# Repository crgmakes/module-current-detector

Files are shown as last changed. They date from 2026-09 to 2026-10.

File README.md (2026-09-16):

# Current Detector Module

All the source files for the current detector module hardware.

# Software 

You will need [KiCad](https://kicad.org) to view and edit this design. Click [here](https://www.kicad.org/download/) to download.

You will also need all the associated libraries and models to drive the design if you want to make changes or view the 3D rendering:

https://github.com/crgmakes/kicad-library.git

Kicad MUST be configured properly to use all the files in this repo. Once you have Kicad installed, under Preferences->Configure Paths..., make the following entries:

1. - KICAD_USER_DIR -> set to the root location of where you placed the above repository.
2. - KICAD_USER_LIBRARY = ${KICAD_USER_DIR}/Library
3. - KICAD_USER_MODEL_DIR = ${KICAD_USER_LIBRARY}/models
4. - KICAD_USER_TEMPLATE_DIR	= ${KICAD_USER_LIBRARY}/templates	

Kicad will operate mostly normally if these are not set properly. You will notice an issue when you view the PCB in 3D mode.

***NOTE***: after makeing a release build in git, if your rendered 3D images are missing components, ensure the path to EVERY component model is set to ${KICAD_USER_MODEL_DIR}/<model name>.

Kicad sometimes replaces the variable with an expansion and that FAILS during the build process because the expanded variable is local and does not match the build environment.

---

THE DESIGN IS PROVIDED "AS IS" AND THE AUTHOR DISCLAIMS ALL WARRANTIES WITH REGARD TO THIS DESIGN INCLUDING ALL IMPLIED WARRANTIES OF MERCHANTABILITY AND FITNESS. IN NO EVENT SHALL THE AUTHOR BE LIABLE FOR ANY SPECIAL, DIRECT, INDIRECT, OR CONSEQUENTIAL DAMAGES OR ANY DAMAGES WHATSOEVER RESULTING FROM LOSS OF USE, DATA OR PROFITS, WHETHER IN AN ACTION OF CONTRACT, NEGLIGENCE OR OTHER TORTIOUS ACTION, ARISING OUT OF OR IN CONNECTION WITH THE USE OR PERFORMANCE OF THIS DESIGN.

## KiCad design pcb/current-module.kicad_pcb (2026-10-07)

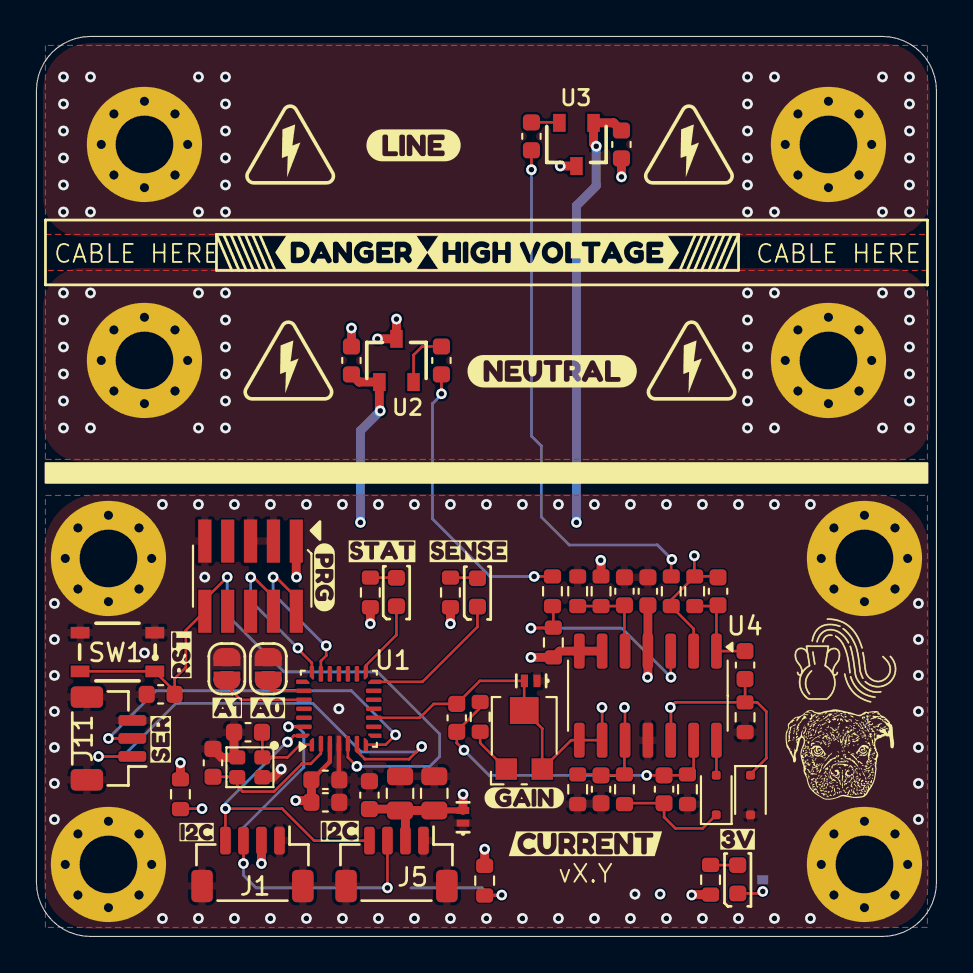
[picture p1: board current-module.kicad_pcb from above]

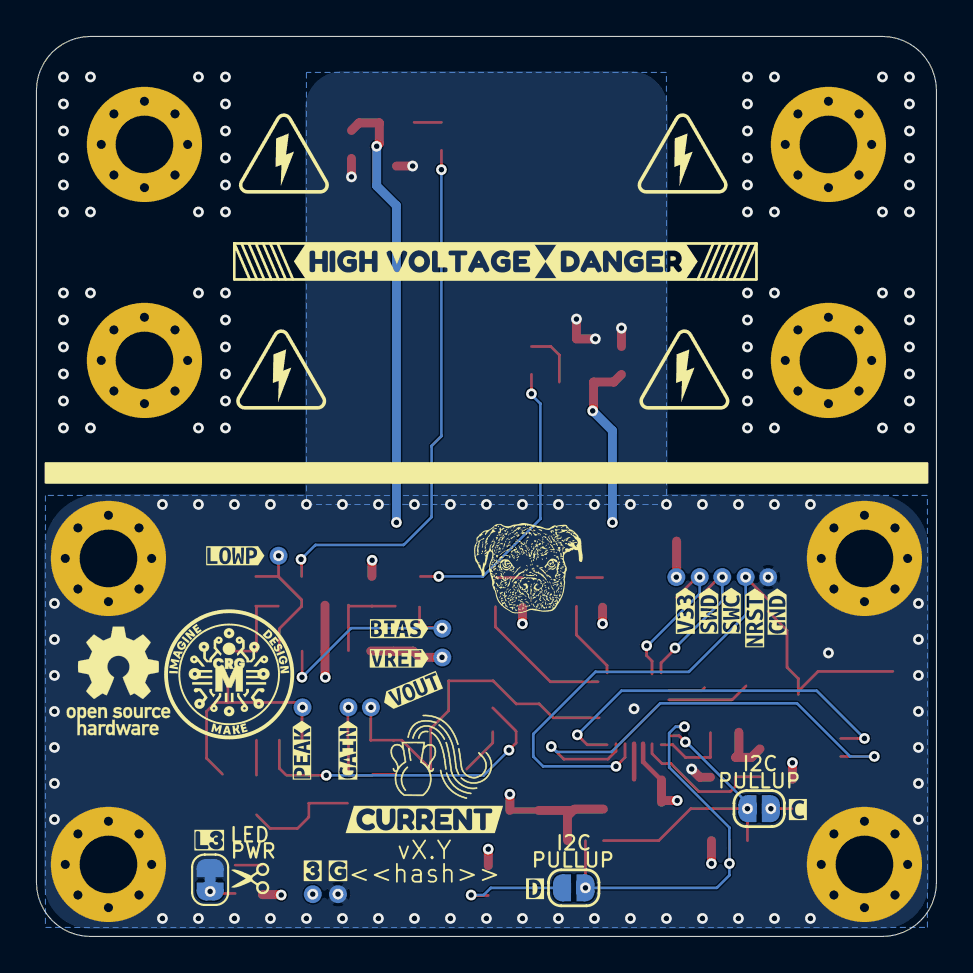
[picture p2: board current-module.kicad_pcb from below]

Board: 4 copper layers, 50.0 x 50.0 mm, 128 parts (43 on the bottom side), 39 nets.

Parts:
C1, C2: 4.7pF; C_0603_1608Metric
C3: 4.7uF; C_0603_1608Metric
C4, C5, C9, C11, C12: 0.1uF; C_0603_1608Metric
C6, C14: 10uF; C_0603_1608Metric
C7, C8: 1uF; C_0603_1608Metric
C10: 2nF; C_0603_1608Metric
C13, C16: 47uF; C_0805_2012Metric
C15, C17, C18, C19: 0.22uF; C_0603_1608Metric
D1, D2, D9: Blue; LED_0603_1608Metric
D6, D12: PESD3V3S1BL; DFN1006-2
D10, D11: BAT54J; D_SOD-323F
H1, H2, H3, H4, H5, H6, H7, H8: MountingHole_3.2mm_M3_Pad_Via
J1, J5: JST_SH_BM04B-SRSS-TB_1x04-1MP_P1.00mm_Vertical
J2: SWD Header; PinHeader_2x05_P1.27mm_Vertical_SMD
J11: JST_SH_BM03B-SRSS-TB_1x03-1MP_P1.00mm_Vertical
JP1, JP3, JP4, JP5: SolderJumper_2_Open; SolderJumper-2_P1.3mm_Open_RoundedPad1.0x1.5mm
JP2: SolderJumper-2_P1.3mm_Bridged_RoundedPad1.0x1.5mm
LOGO1: CRGM Logo 7mm
LOGO2, LOGO5: Roxy 6.5mm
LOGO3, LOGO7: Aquarius Logo 5mm
LOGO4: OSHW-Logo_5.7x6mm_SilkScreen
R1, R2: 4.7K; R_0603_1608Metric
R3, R7, R15: 1K; R_0603_1608Metric
R8, R9, R16, R19: 100K; R_0603_1608Metric
R10, R13: 300K; R_0603_1608Metric
R11, R12, R17: 4.99K; R_0603_1608Metric
R14: 1M; R_0603_1608Metric
R18: 10M; R_0603_1608Metric
RV1: 1M; Bourns_TC33X_Vertical
SW1: SKRPABE010; SMD-4P-4.2x3.2mm
SYM1, SYM2, SYM3, SYM4, SYM5, SYM6, SYM7, SYM8: HIGH-VOLTAGE-5MM
TP1, TP2, TP3, TP4, TP5, TP6, TP7, TP8, TP9, TP10, TP11, TP21, TP22: TestPoint_Pad_D1.0mm
U1: STM32C051G8Ux; QFN-28_4x4mm_P0.5mm
U2, U3: A1324LLHLT-T; SOT23W
U4: TLV9064; SOIC-14_3.9x8.7mm_P1.27mm
Y1: ECS-480-10-37B2-RWN-TR; Crystal_SMD_2016-4Pin_2.0x1.6mm
kibuzzard-6A2A39A2: G***; kibuzzard-6A2A39A2
kibuzzard-6A2A39A9: G***; kibuzzard-6A2A39A9
kibuzzard-6A2A39B0: G***; kibuzzard-6A2A39B0
kibuzzard-6A2EE621: G***; kibuzzard-6A2EE621
kibuzzard-6A2EE631: G***; kibuzzard-6A2EE631
kibuzzard-6AA9ECA7: G***; kibuzzard-6AA9ECA7
kibuzzard-6AA9ECB3: G***; kibuzzard-6AA9ECB3
kibuzzard-6AA86EAA: G***; kibuzzard-6AA86EAA
kibuzzard-6AA87D7C: G***; kibuzzard-6AA87D7C
kibuzzard-6AA87D56: G***; kibuzzard-6AA87D56
kibuzzard-6AA87D62: G***; kibuzzard-6AA87D62
kibuzzard-6AA87D95: G***; kibuzzard-6AA87D95
kibuzzard-6AA87DA8: G***; kibuzzard-6AA87DA8
kibuzzard-6AA87DBE: G***; kibuzzard-6AA87DBE
kibuzzard-6AA873A0: G***; kibuzzard-6AA873A0
kibuzzard-6AA87368: G***; kibuzzard-6AA87368
kibuzzard-6AA87389: G***; kibuzzard-6AA87389
kibuzzard-6AA87512: G***; kibuzzard-6AA87512
kibuzzard-6AA87574: G***; kibuzzard-6AA87574
kibuzzard-6AAB4A0C: G***; kibuzzard-6AAB4A0C
kibuzzard-6AAB503A: G***; kibuzzard-6AAB503A
kibuzzard-6AAB5003: G***; kibuzzard-6AAB5003
kibuzzard-6AAB5046: G***; kibuzzard-6AAB5046
kibuzzard-6AAB5059: G***; kibuzzard-6AAB5059
kibuzzard-6AAB5063: G***; kibuzzard-6AAB5063
kibuzzard-68F7E62B, kibuzzard-68F7E62B#2: G***; kibuzzard-68F7E62B
kibuzzard-68F7E620, kibuzzard-68F7E620#2: G***; kibuzzard-68F7E620
kibuzzard-690A7DF7: G***; kibuzzard-690A7DF7
kibuzzard-690AC3CC: G***; kibuzzard-690AC3CC
kibuzzard-690AC3D2: G***; kibuzzard-690AC3D2
kibuzzard-690D5FD9: G***; kibuzzard-690D5FD9
kibuzzard-690D5FF2: G***; kibuzzard-690D5FF2
kibuzzard-6954A310: G***; kibuzzard-6954A310

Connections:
+3.3V: C3.1, C4.1, C9.1, C11.1, C13.1, C14.1, C15.1, C16.1, D6.2 (K2), J1.2, J2.1 (VTref), J5.2, R1.2, R2.2, R3.1, R7.1, R8.1, R15.1, TP2.1 (1_1), TP21.1 (1_1), U1.3 (VDD), U2.1 (VCC), U3.1 (VCC), U4.4 (V+)
/Current Sensor/DCBIAS: R10.1, R12.1, TP7.1 (1_1), U4.3 (+)
/Current Sensor/GAIN: C18.2, R17.1, R18.1, TP10.1 (1_1), U4.10 (+)
/Current Sensor/H1IN: C8.2, R12.2
/Current Sensor/H2IN: C7.2, R11.2
/Current Sensor/HALL1: C8.1, U2.2 (VOUT)
/Current Sensor/HALL2: C7.1, U3.2 (VOUT)
/Current Sensor/LOWPASS: C10.1, R11.1, R13.2, TP8.1 (1_1), U4.2 (-)
/Current Sensor/PEAK: C12.2, D10.1 (K), R14.1, TP9.1 (1_1), U4.12 (+)
/MCU/A0: JP4.2 (B), U1.23 (PB3)
/MCU/A1: JP5.2 (B), U1.24 (PB4)
/MCU/SENSE: D1.1 (K), U1.14 (PB0)
/MCU/STATUS: D9.1 (K), U1.15 (PB1)
/Power/Line: H5.1 (1_1), H6.1 (1_1)
/Power/Neutral: H7.1 (1_1), H8.1 (1_1)
/Power/V3.3LED: D2.2 (A), R15.2
GND: C1.1, C2.1, C3.2, C4.2, C5.2, C6.2, C9.2, C11.2, C13.2, C14.2, C15.2, C16.2, C18.1, D6.1 (K1), D10.2 (A), D12.1 (K1), H1.1 (1_1), H2.1 (1_1), H3.1 (1_1), H4.1 (1_1), J1.0 (MP), J1.1, J1.5 (MP), J2.3 (GND), J2.5 (GND), J2.9 (GNDDetect), J5.0 (MP), J5.1, J5.5 (MP), J11.0 (MP), J11.3, J11.4 (MP), JP2.1 (A), JP4.1 (A), JP5.1 (A), R9.2, R14.2, R16.2, R18.2, SW1.3, SW1.4, TP1.1 (1_1), TP22.1 (1_1), U1.4 (VSS), U2.3 (GND), U3.3 (GND), U4.11 (V-), Y1.2 (G), Y1.4 (G)
IO1: C19.2, D12.2 (K2), RV1.2, RV1.3, TP11.1 (1_1), U1.10 (PA4), U4.8, U4.9 (-)
NRST: C5.1, J2.10 (~RESET), SW1.1, SW1.2, TP3.1 (1_1), U1.5 (PF2-NRST)
unnamed: C10.2, C12.1, R13.1, U4.1
unnamed: D1.2 (A), R3.2
unnamed: D2.1 (K), JP2.2 (B)
unnamed: D9.2 (A), R7.2
unnamed: D11.2 (A), U4.14
unnamed: C17.2, D11.1 (K), R17.2
unnamed: JP1.2 (B), R1.1
unnamed: JP3.2 (B), R2.1
unnamed: R19.1, RV1.1
unnamed: C2.2, U1.1 (PC14/OSCXIN), Y1.1
unnamed: C1.2, U1.2 (PC15/OSCXO), Y1.3
unnamed: C6.1, R8.2, R9.1, U4.5 (+)
unnamed: C17.1, C19.1, R16.1, R19.2, U4.13 (-)
RXD: J11.2, U1.7 (PA1)
SCL: J1.4, J5.4, JP1.1 (A), U1.28 (PB8)
SDA: J1.3, J5.3, JP3.1 (A), U1.27 (PB7)
SWCLK: J2.4 (SWDCLK/TCK), TP4.1 (1_1), U1.21 (PA14-BOOT0)
SWDIO: J2.2 (SWDIO/TMS), TP5.1 (1_1), U1.20 (PA13)
TXD: J11.1, U1.6 (PA0)
VREF: R10.2, TP6.1 (1_1), U4.6 (-), U4.7

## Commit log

2025-04-09 Initial checkin
    [current-mod-ac.kicad_sch, current-mod-sensor.kicad_sch, current-mod-uc.kicad_sch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]
2025-07-13 Update .gitignore and clarify KiCAD library license
    Added .DS_Store to .gitignore to prevent macOS system files from being tracked. Updated LICENSE.md to clarify that KiCAD libraries are available in the 'kicad-library' repo under CC BY-SA 4.0.
2025-08-14 Reworked to be headless module
    [current-mod-ac.kicad_sch, current-mod-sensor.kicad_sch, current-mod-uc.kicad_sch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]
2025-08-14 Set stackup; added pics to root; minor graphics editing; fixed models
    [current-sensor.kicad_sch, requirements.kicad_sch]
2025-08-15 Fixed spacing and model orgin
    [current-module.csv]
2025-08-16 Fixed production errors
    [current-sensor.kicad_sch]
2025-08-16 Changed resistor and cap footprints to CRGM
    [current-sensor.kicad_sch, power.kicad_sch]
2025-08-16 Added via to ground test point; minor routing changes; updated renders
    [current-sensor.kicad_sch]
2025-08-19 Fixed silkscreen placement
2025-08-21 Fixed part values; added name to scripts
    [current-sensor.kicad_sch]
2025-08-23 Removed CSV bom file; moved logos to symbols
    [current-module.csv, current-sensor.kicad_sch, power.kicad_sch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]
2025-08-24 Minor placement moves to better routing; updated requirements
    [requirements.kicad_sch]
2025-08-25 Updated design considerations; rerouted gain pot and signals
    [requirements.kicad_sch]
2025-08-25 Updated to all CRGM footprints
    [current-sensor.kicad_sch, power.kicad_sch]
2025-09-09 Updated part properties for consistency
    [current-sensor.kicad_sch, power.kicad_sch]
2025-09-09 Fixed line thickness
    Moved logos
    Fixed board fillet to 3mm
    [power.kicad_sch, requirements.kicad_sch]
2025-09-10 Rerouted analog in AC section
    Moved power LED
    Added additional silkscreen
    Updated renders
    [requirements.kicad_sch]
2025-09-11 Updated symbol with new designator
    [requirements.kicad_sch]
2025-10-21 Redesign with MCU
    [current-sensor.kicad_sch, interfaces.kicad_sch, mcu.kicad_sch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]
2025-10-21 Clean up, arranging, ERC and DCR
    [current-sensor.kicad_sch, interfaces.kicad_sch, power.kicad_sch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]
2025-10-22 Added renders to schematics
    Minor clean up
2025-10-22 Fixed LCSC part numbers and attributes
    [current-sensor.kicad_sch, interfaces.kicad_sch, mcu.kicad_sch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]
2025-10-24 Adjusted BOM settings
    [mcu.kicad_sch]
2025-10-26 Tightened to 50mm wide
    SO MUCH fiddling!
    Changed I2C to single jumpers
    [mcu.kicad_sch, requirements.kicad_sch]
2025-11-03 Updates for consistency
    Changed mounting holes to grounded
    Updated power connectors
    [interfaces.kicad_sch, mcu.kicad_sch, power.kicad_sch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]
2025-11-07 Fixed model paths and silkscreen
2025-11-19 Added FNWW to silkscreen
    Updated renders on schematics
    [requirements.kicad_sch]
2025-11-22 Updated part for availability and price
    Adjusted origin.
    [current-sensor.kicad_sch]
2025-11-22 Updated parts for cost
    [current-sensor.kicad_sch]
2025-11-25 Added TVS to ADC for spikes; still investigating
    [current-sensor.kicad_sch]
2025-12-16 Swapped parts based on availability
    Added additional filtering caps
    [power.kicad_sch]
2025-12-30 Removed power connectors
    Removed power connector as 5v is not necessary.
    Added 100uF caps to power
    Added TVS to I2C and VOUT
    Rerouted entire board
    Adjusted silkscreen
    [interfaces.kicad_sch, mcu.kicad_sch, power.kicad_sch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]
2026-03-19 Collapsed UPDI and Serial
    Added indicator LEDs
    Rerouted
    Cleaned up silkscreen
    [current-sensor.kicad_sch, interfaces.kicad_sch, mcu.kicad_sch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]
2026-03-20 Updated models and paths
    [current-sensor.kicad_sch, power.kicad_sch]
2026-03-22 Fixed MCU Footprint
    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
    [current-sensor.kicad_sch, interfaces.kicad_sch, mcu.kicad_sch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]
2026-03-23 Fixed model path
    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
2026-04-05 Close #1
    Added labels to all test points
    Moved 3.3 and GND test points
    Added labels to top as well as bottom
    [mcu.kicad_sch]
2026-06-15 fixed extra spaces and sheet numbers
    [current-sensor.kicad_sch, interfaces.kicad_sch, mcu.kicad_sch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]
2026-06-15 Updated footprints
    [current-sensor.kicad_sch, interfaces.kicad_sch, mcu.kicad_sch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]
2026-06-15 Added PCB template title block
2026-06-16 Updated part descriptions and models
    [current-sensor.kicad_sch, interfaces.kicad_sch, mcu.kicad_sch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]
2026-09-14 refactored to STM32
    [current-module-old.kicad_pcb, current-module.kicad_pcb, current-module.kicad_sch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]
2026-09-14 removed old file
    [current-module-old.kicad_pcb]
2026-09-16 Added additional silkscreen to AC side
    [current-module.kicad_pcb, mcu.kicad_sch, power.kicad_sch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]
2026-09-16 Added renders. Fixed PCB title
    [current-module.kicad_pcb, current-module.kicad_sch]
2026-09-17 Moved prg connector
    Silkscreen updates
    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
    [current-module.kicad_pcb, current-module.kicad_sch]
2026-09-18 Updated part silkscreen
    [current-module.kicad_pcb]
2026-09-19 Fixed board outline end point
    [current-module.kicad_pcb]
2026-10-07 Nothing significant
    [current-module.kicad_pcb]
2026-10-16 Removed AC input via copper
    Testing revealed sending AC through copper did not trigger device. Removed ability to send AC through the PCB.
2026-10-29 Added alternative part numbers for LCSC
    Moved silkscreen a little
    Updated requirements to indicate 1oz cu vs 2oz.
